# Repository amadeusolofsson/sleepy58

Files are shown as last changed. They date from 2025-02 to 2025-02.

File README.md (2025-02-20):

# sleepy58 (WARNING. DONGLE STILL NOT WORKING PERFECTLY FIRMWARE. AND MY THUMB CLUSTER IS FUCKED AND IS WIRED HORRIBLY AND DOESN'S WORK CORRECTLY. NEED TO FIX ERGOGEN. ALSO THE THUMBS ARE VERY UNCOMFORTABLE)

## A low-profile 4x6 orthocolumnar wireless keyboard with a 5-key thumb cluster. 
It uses [ZMK](https://github.com/zmkfirmware/zmk) together with the Seeed Studio XIAO BLE nRF52840.
I created it using [ergogen](https://github.com/ergogen/ergogen). Putting the pcb file into kiCad and routing it.
I used some of [ceoloide's](https://github.com/ceoloide/ergogen-footprints/tree/main) footprints for ergogen.

## Required Parts

| Part name | Count | Description and sites I bought from (Many swedish ones, just use something equivalent) |
| :---| :---: | :---|
| PCBs | 2 | Flippable so only two needed. (I bought from JLCPCB, lead-free, 2 layers) |
| XIAO Wireless MCUs  | 3 | 1 each side (+1 if you want to use as dongle) https://www.digikey.se/en/products/detail/seeed-technology-co-ltd/102010448/16652893?so=90838492  |
| Choc Switches v1 |  58 | 58 Low Profile Choc switches (29 for each hand) https://splitkb.com/products/ambients-kailh-low-profile-choc-switches?variant=48116119830875 |
| diodes 1N4148W |  58 | 58 SOD123 SMD Diodes https://www.digikey.se/en/products/detail/diodes-incorporated/1N4148W-7-F/814371?so=9083849 |
| Choc Keycaps |  58 | 58 Choc v1 Compatible Keycaps https://splitkb.com/products/blank-mbk-choc-low-profile-keycaps?variant=31811491987533 |
| Power Switches | 2 | For switching battery power https://www.electrokit.com/en/skjutomkopplare-mini-1-pol-on-on-smd |
| JST Plugs | 2 | For connecting battery easily https://www.electrokit.com/stiftlist-ph-2-pol-2.0mm-vinklad-1 |
| Lipo batteries | 2 | Small battery https://www.electrokit.com/batteri-lipo-3.7v-380mah |
| Rubber feet |  8 | Since no case https://www.electrokit.com/3m-bumpon-gummifot-6.4x1.9mm-8-pack |
| Dongle casing | 1 | Optional casing for dongle https://www.printables.com/model/522586-seeed-xiao-ble-case | 

## Recognitions and thanks
Ben Vallack and Christian Selig for inspiration.
@GEIGEIGEIST & @Pipshag as great examples to compare my own keyboard with for when I got stuck on a specific part.
@VOID for the 3d printed dongle casing files.
And finally massive thanks to the ZMK & Absolem Club discords and it's members who helped me with my stupid questions :)

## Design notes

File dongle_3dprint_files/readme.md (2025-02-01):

Files came from here: https://www.printables.com/model/522586-seeed-xiao-ble-case by @VOID

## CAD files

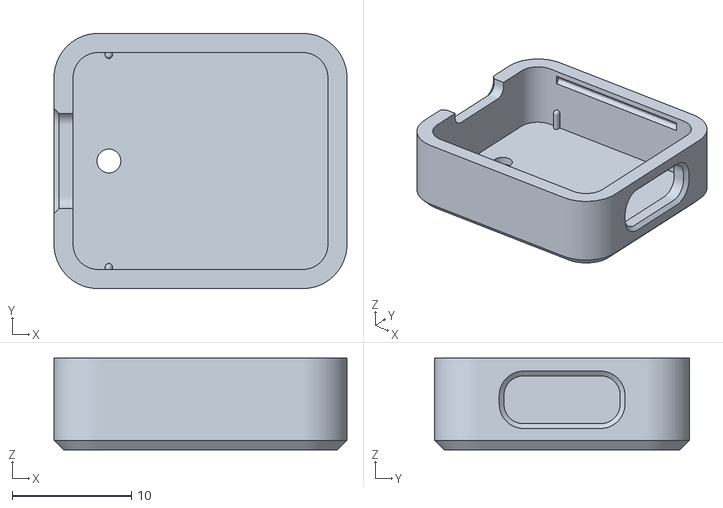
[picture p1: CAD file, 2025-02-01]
dongle_3dprint_files/xiao_dongle_bottom.stl
24.6 x 21.4 x 7.70

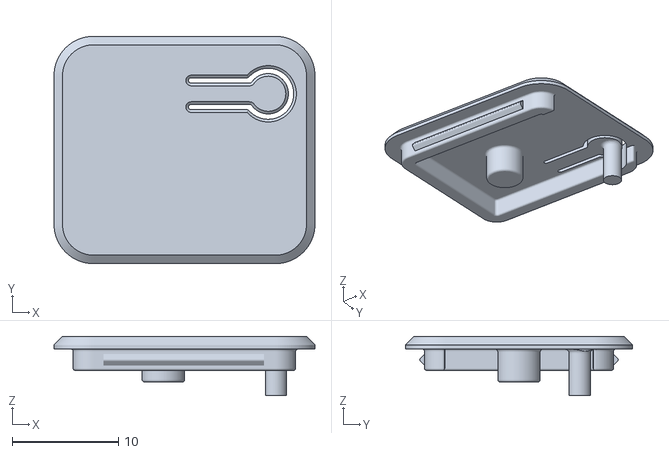
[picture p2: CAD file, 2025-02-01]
dongle_3dprint_files/xiao_dongle_top.stl
24.6 x 21.4 x 5.57

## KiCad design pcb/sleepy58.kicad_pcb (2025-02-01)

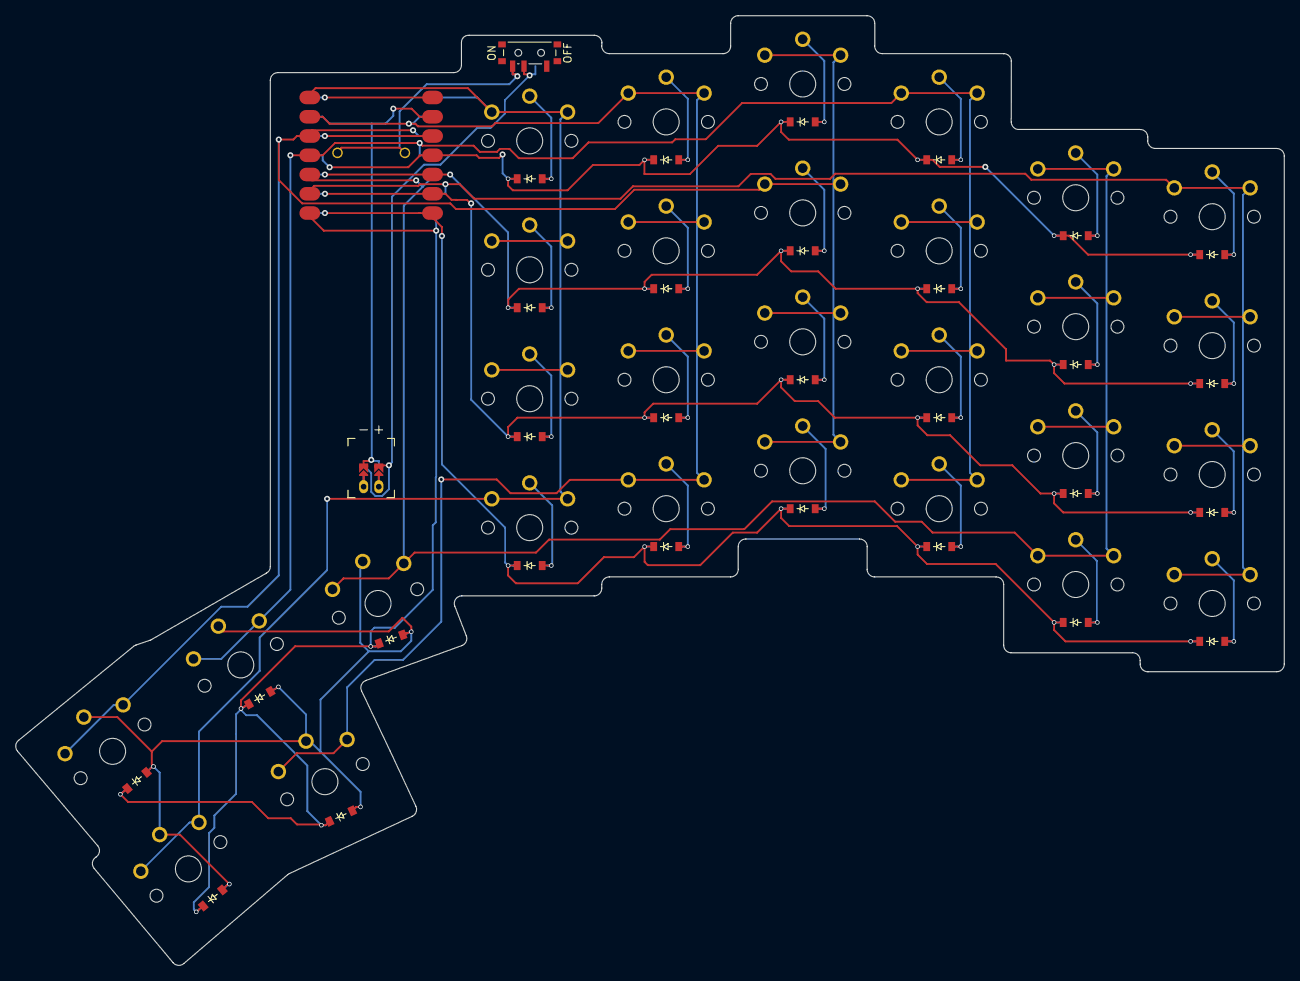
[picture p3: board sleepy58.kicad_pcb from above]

Board: 2 copper layers, 167.3 x 125.2 mm, 61 parts (0 on the bottom side), 41 nets.

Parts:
D1, D2, D3, D4, D5, D6, D7, D8, D9, D10, D11, D12, D13, D14, D15, D16, D17, D18, D19, D20, D21, D22, D23, D24, D25, D26, D27, D28, D29: diode_tht_sod123
JST1: battery_connector_jst_ph_2
MCU1: xiao-ble-smd-reversible
PWR1: power_switch_smd_side
S1, S2, S3, S4, S5, S6, S7, S8, S9, S10, S11, S12, S13, S14, S15, S16, S17, S18, S19, S20, S21, S22, S23, S24, S25, S26, S27, S28, S29: PG1350

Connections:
BBAT+: JST1.1, PWR1.2
C0: MCU1.1, S1.1, S2.1, S3.1, S4.1, S29.1
C1: MCU1.2, S5.1, S6.1, S7.1, S8.1, S28.1
C2: MCU1.3, S9.1, S10.1, S11.1, S12.1, S27.1
C3: MCU1.4, S13.1, S14.1, S15.1, S16.1, S26.1
C4: MCU1.5, S17.1, S18.1, S19.1, S20.1, S25.1
C5: MCU1.6, S21.1, S22.1, S23.1, S24.1
GND: JST1.2, MCU1.13
JST1_1: JST1.11, JST1.21, JST1.31
JST1_2: JST1.12, JST1.22, JST1.32
R0: D25.1, D26.1, D27.1, D28.1, D29.1, MCU1.7
R1: D1.1, D5.1, D9.1, D13.1, D17.1, D21.1, MCU1.8
R2: D2.1, D6.1, D10.1, D14.1, D18.1, D22.1, MCU1.9
R3: D3.1, D7.1, D11.1, D15.1, D19.1, D23.1, MCU1.10
R4: D4.1, D8.1, D12.1, D16.1, D20.1, D24.1, MCU1.11
XBAT+: MCU1.19, PWR1.1, PWR1.3
default_default: D25.2, D26.2, D27.2, D28.2, D29.2, S25.2, S26.2, S27.2, S28.2, S29.2
index_bottom: D17.2, S17.2
index_home: D18.2, S18.2
index_num: D20.2, S20.2
index_top: D19.2, S19.2
inner_bottom: D21.2, S21.2
inner_home: D22.2, S22.2
inner_num: D24.2, S24.2
inner_top: D23.2, S23.2
middle_bottom: D13.2, S13.2
middle_home: D14.2, S14.2
middle_num: D16.2, S16.2
middle_top: D15.2, S15.2
outer_bottom: D1.2, S1.2
outer_home: D2.2, S2.2
outer_num: D4.2, S4.2
outer_top: D3.2, S3.2
pinky_bottom: D5.2, S5.2
pinky_home: D6.2, S6.2
pinky_num: D8.2, S8.2
pinky_top: D7.2, S7.2
ring_bottom: D9.2, S9.2
ring_home: D10.2, S10.2
ring_num: D12.2, S12.2
ring_top: D11.2, S11.2
